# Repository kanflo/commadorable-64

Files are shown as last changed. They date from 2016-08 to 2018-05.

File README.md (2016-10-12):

# Commadorable 64

An adorable Commodore 64 desktop ornament. Blog post [here](http://johan.kanflo.com/the-commadorable-64/).

<p align="center">
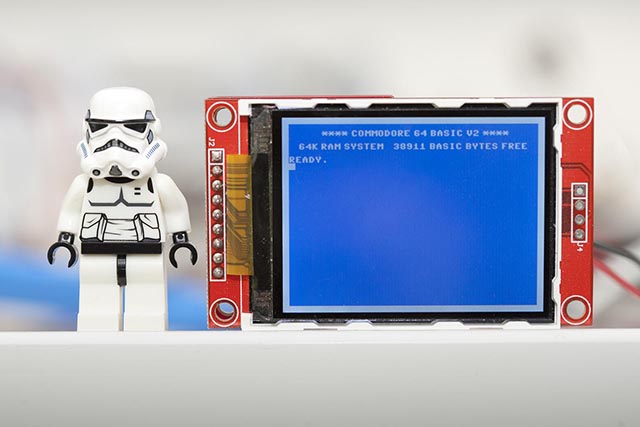
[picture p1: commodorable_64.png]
The Commadorable 64
  
</p>

**Howto**

Assuming you have cloned the EOR git and set your wifi credentials:

```
export EOR_ROOT=/path/to/esp-open-rtos
cd $EOR_ROOT
git clone https://github.com/kanflo/eor-arduino-compat.git extras/arduino-compat
git clone https://github.com/kanflo/eor-adafruit-ili9341.git extras/ili9341
git clone https://github.com/kanflo/eor-cli.git extras/cli
cd /path/to/wherever
git clone https://github.com/kanflo/commadorable-64.git
cd commadorable-64
make -j8 && make flash
```

**Ordering the PCB**

The PCBs can be ordered from DirtyPCBs.com, [without touch](http://dirtypcbs.com/view.php?share=18116&accesskey=5cb9ea9c4754e5c9102b4350393b244e) or [with touch](http://dirtypcbs.com/view.php?share=18114&accesskey=f7144fbd88f9270b40ccc2829f08ee2f). If you use these links to order I will receive a $1 credit :)

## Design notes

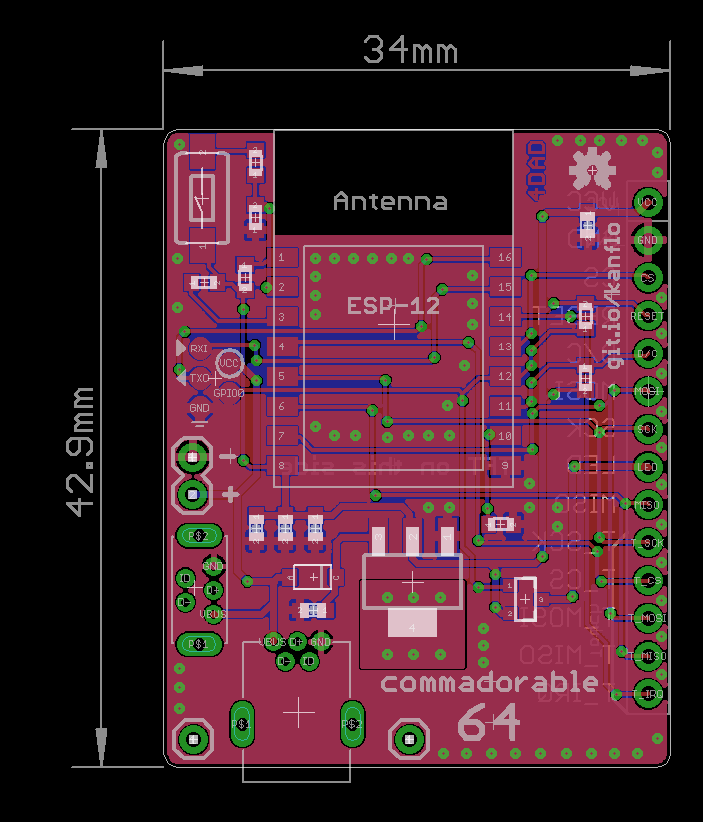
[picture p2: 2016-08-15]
hardware/v1-24-touch/commadorable64-24-touch-v1.png

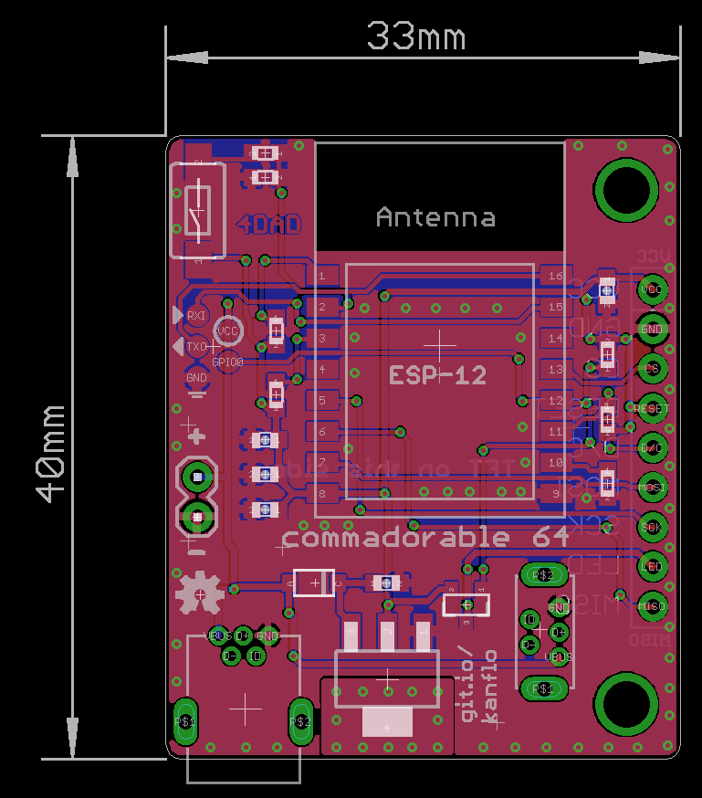
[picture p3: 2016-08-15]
hardware/v1-22/commadorable64-22-v1.png

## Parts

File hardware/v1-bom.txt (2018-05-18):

BOM for Commadoraboe 64 with and without touch

v1-22/        2.2" version without touch
v1-24-touch/  2.4" version with touch
v1-28-touch/  2.8" version with touch

Part Value       Package           Description
------------------------------------------------------------------------------
C1   1uF         0603              Capacitor
C2   0.1uF       0603              Capacitor
C3   1uF         0603              Capacitor
C4   10uF        0603              Capacitor
C5   0.1uF       0603              Capacitor
G1               SOD-123FL         SCHOTTKY DIODE (e.g., MBR120LFST)
J1               1x14              Standard 14-pin 0.1" header
JP1              1X02              Standard 2-pin 0.1" header
JP2, JP3         1X01              For mounting support on C64 touch variant
Q2               SOT23-3           MOSFET-PCHANNEL (e.g.,  IRLML9303)
R1   4k7         R0603             Resistor
R2   4k7         R0603             Resistor
R3   4k7         R0603             Resistor
R4   4k7         R0603             Resistor
R5   4k7         R0603             Resistor
R6   220k        R0603             Resistor
R7   100k        R0603             Resistor
S1               Tactile switch    3x6x2.5mm tactile switch from eBay
U1   3.3V        SOT223            NCP1117ST33 (3.3V LDO)
U2               ESP-12E           ESP12e module
X1                                 Mini USB through hole connector from eBay
X2                                 Vertical Mini USB through hole connector from eBay
X3                                 ESPROG (pads included on PCB, no mounting needed)

Please see http://johan.kanflo.com/the-commadorable-64/ for links to the
switch and USB connectors.

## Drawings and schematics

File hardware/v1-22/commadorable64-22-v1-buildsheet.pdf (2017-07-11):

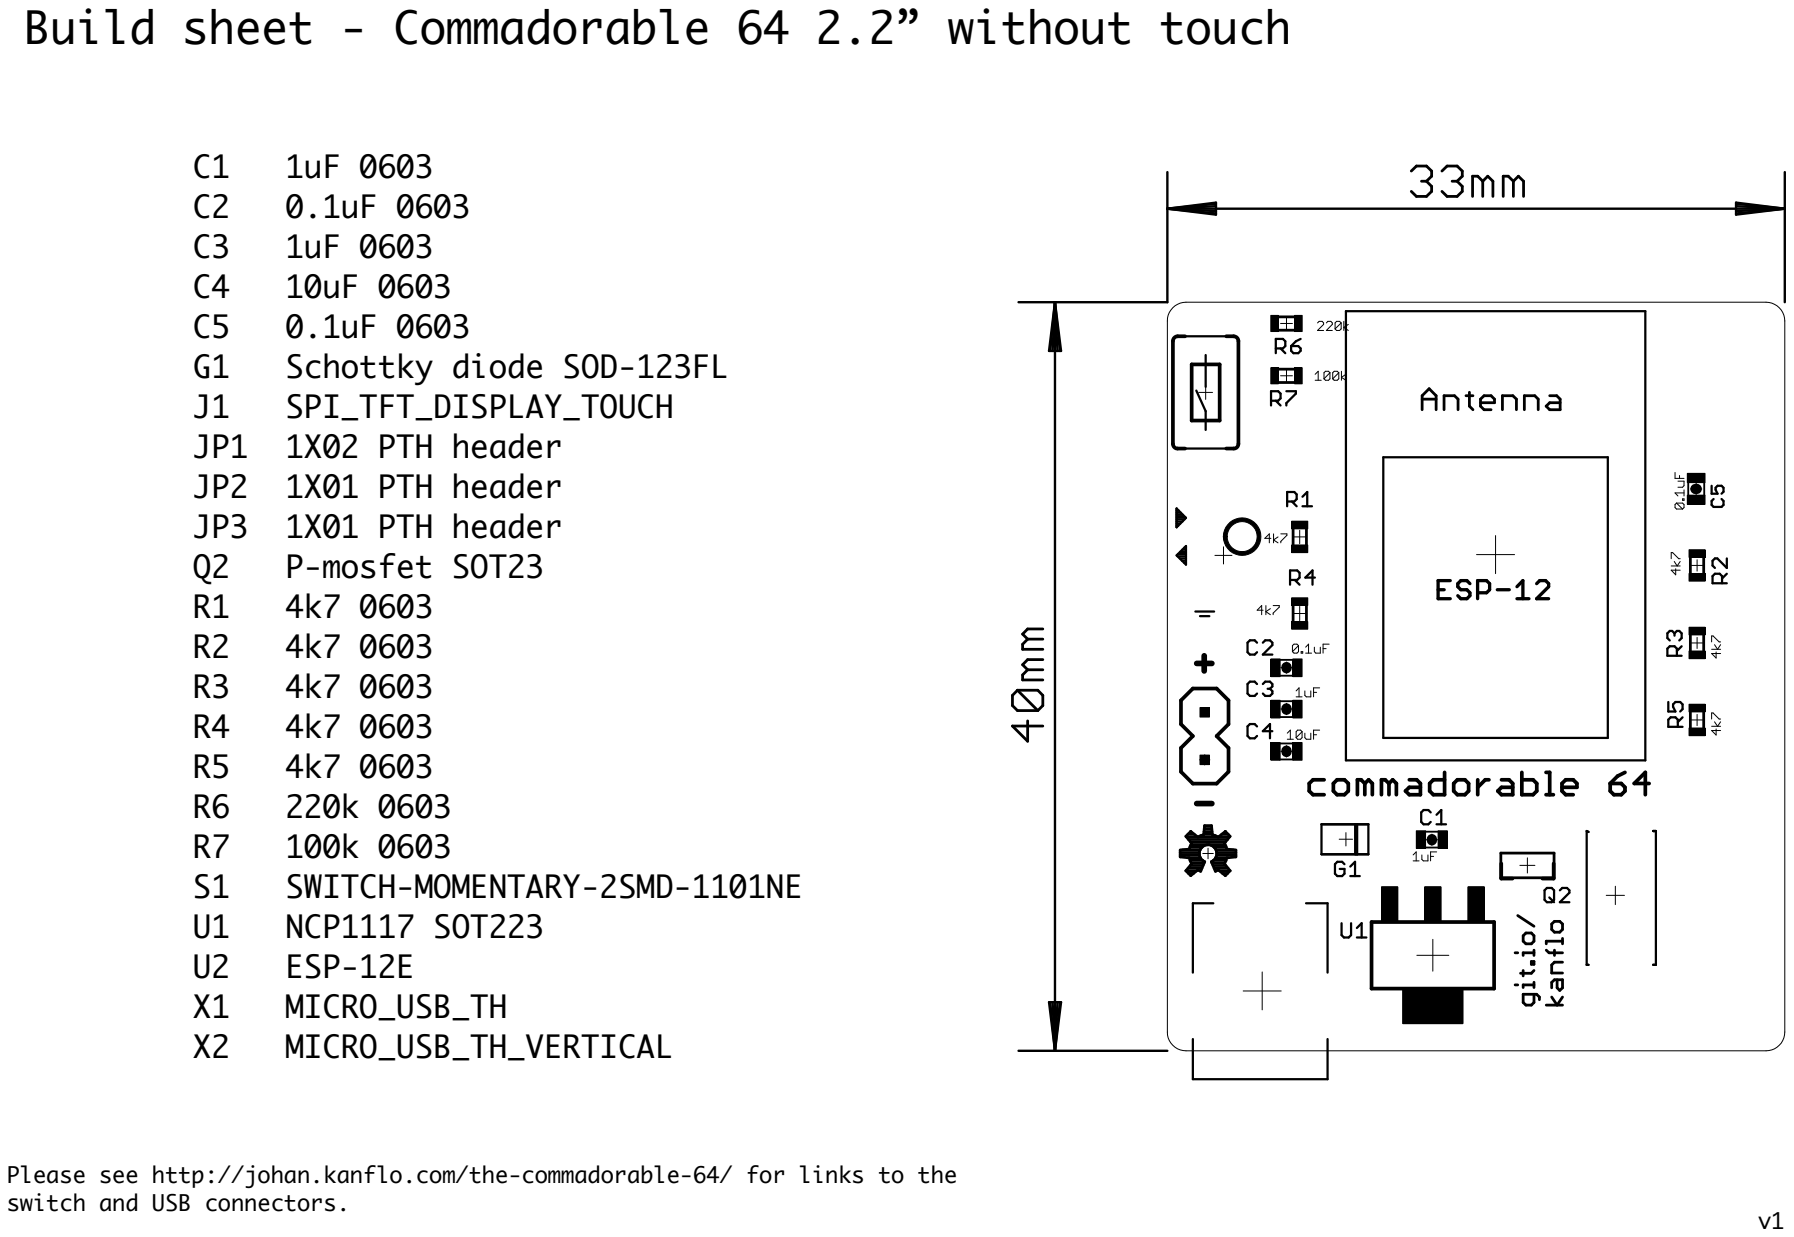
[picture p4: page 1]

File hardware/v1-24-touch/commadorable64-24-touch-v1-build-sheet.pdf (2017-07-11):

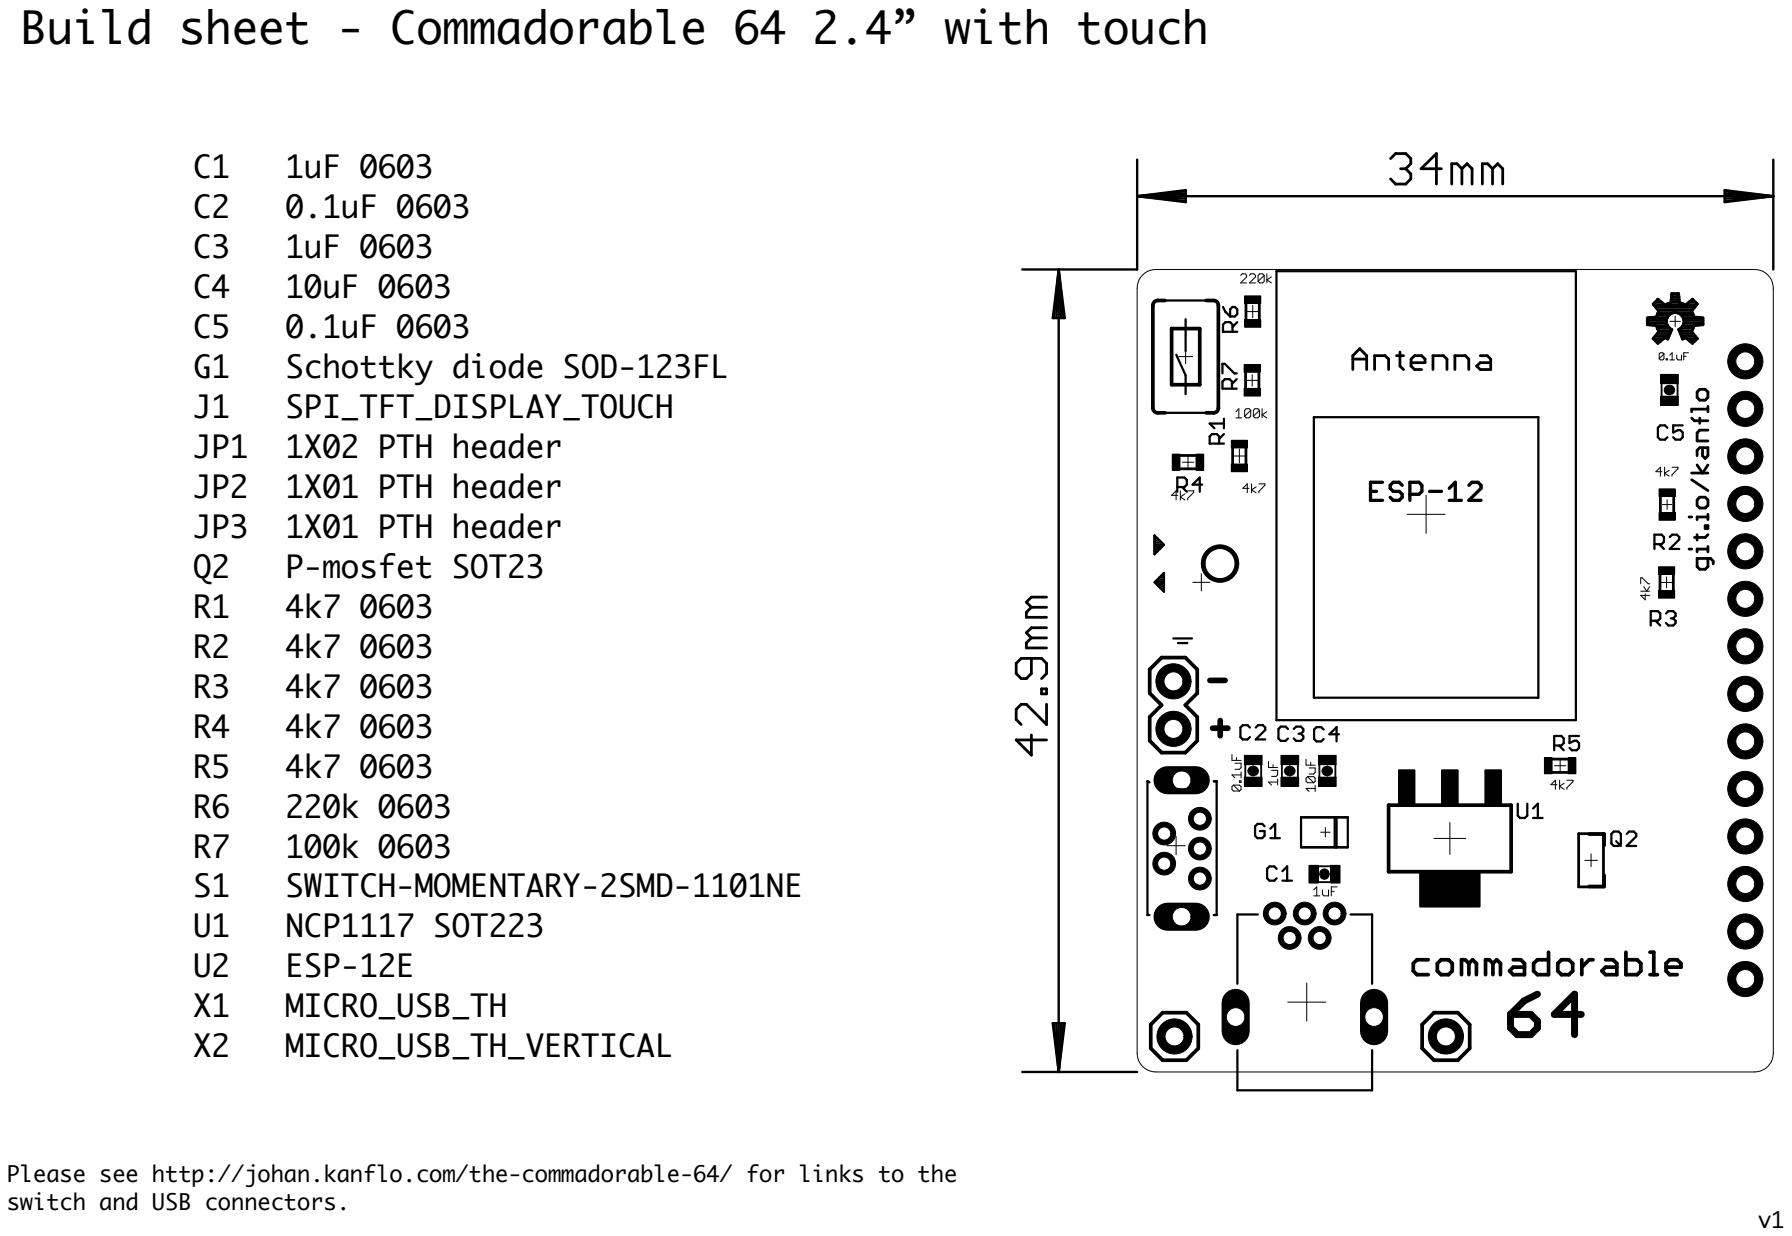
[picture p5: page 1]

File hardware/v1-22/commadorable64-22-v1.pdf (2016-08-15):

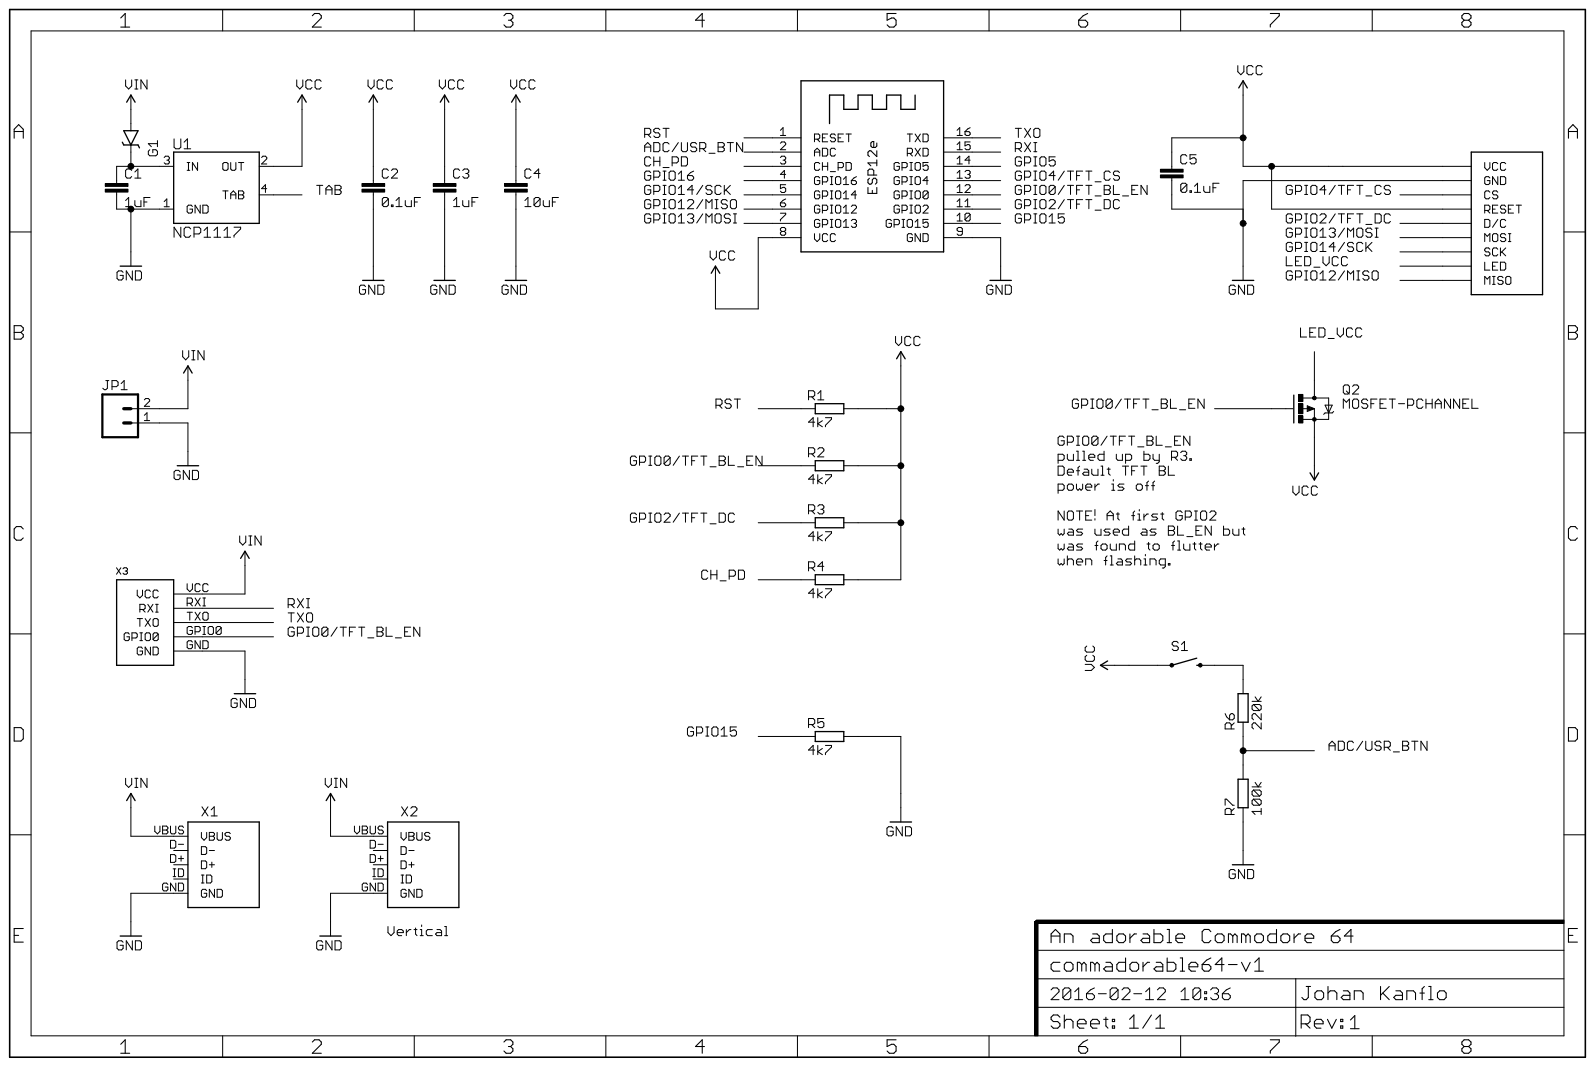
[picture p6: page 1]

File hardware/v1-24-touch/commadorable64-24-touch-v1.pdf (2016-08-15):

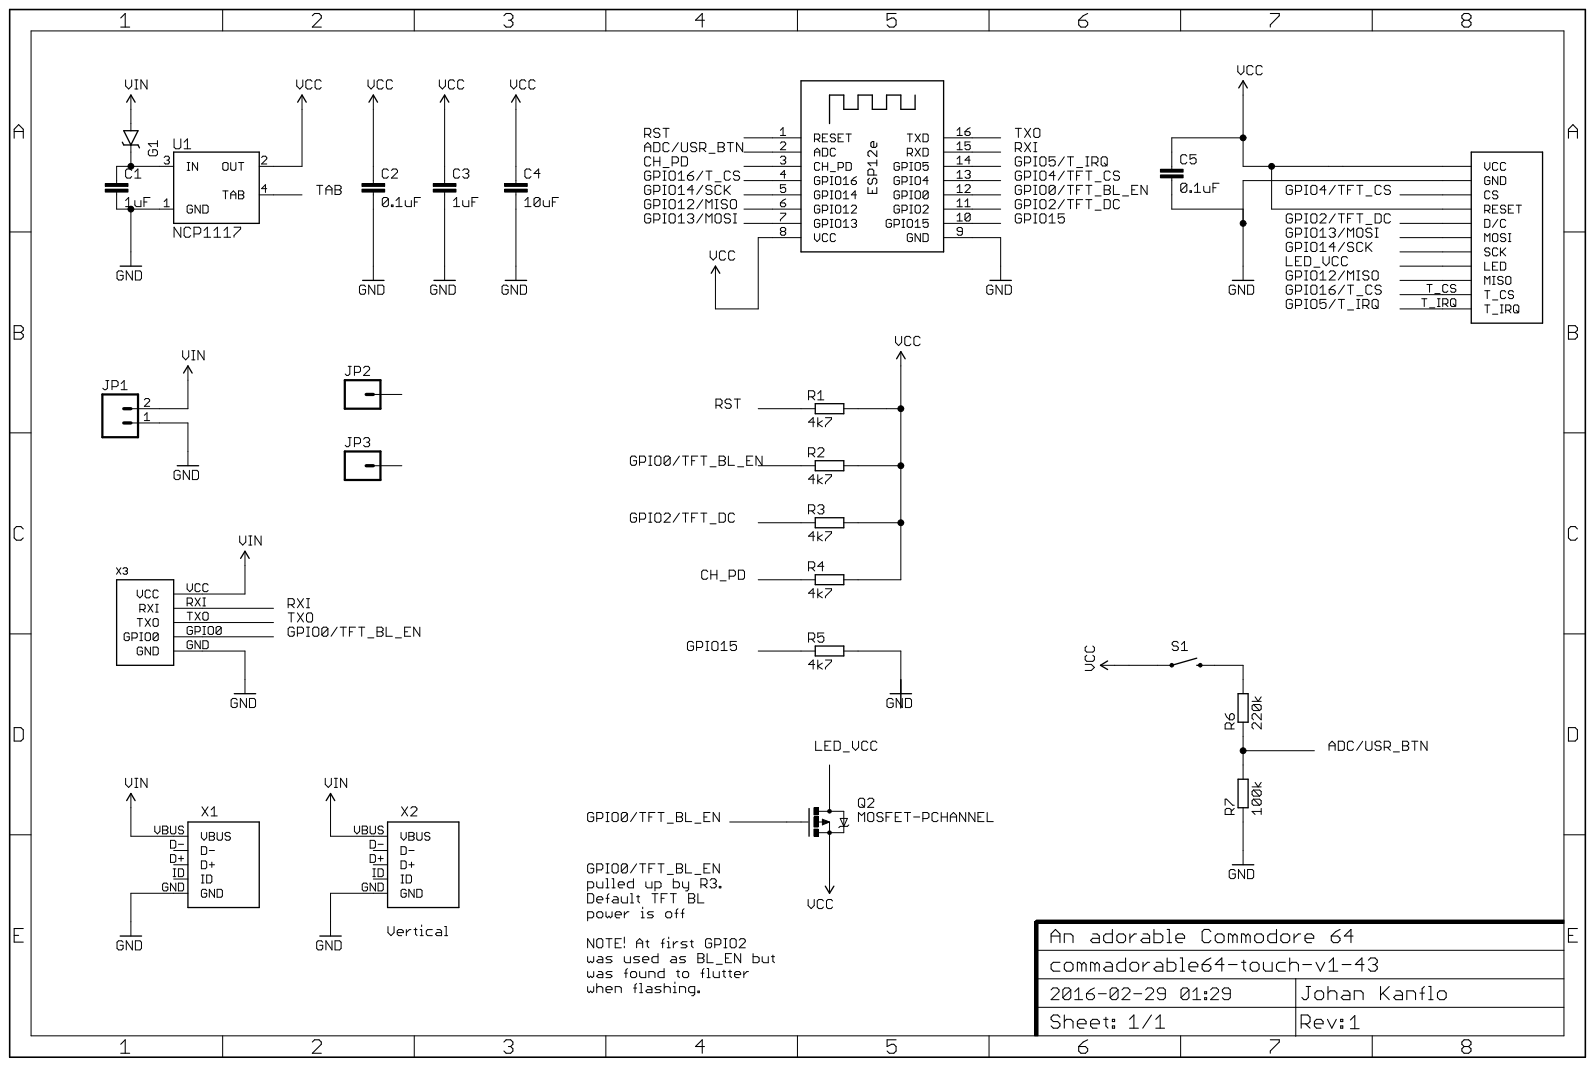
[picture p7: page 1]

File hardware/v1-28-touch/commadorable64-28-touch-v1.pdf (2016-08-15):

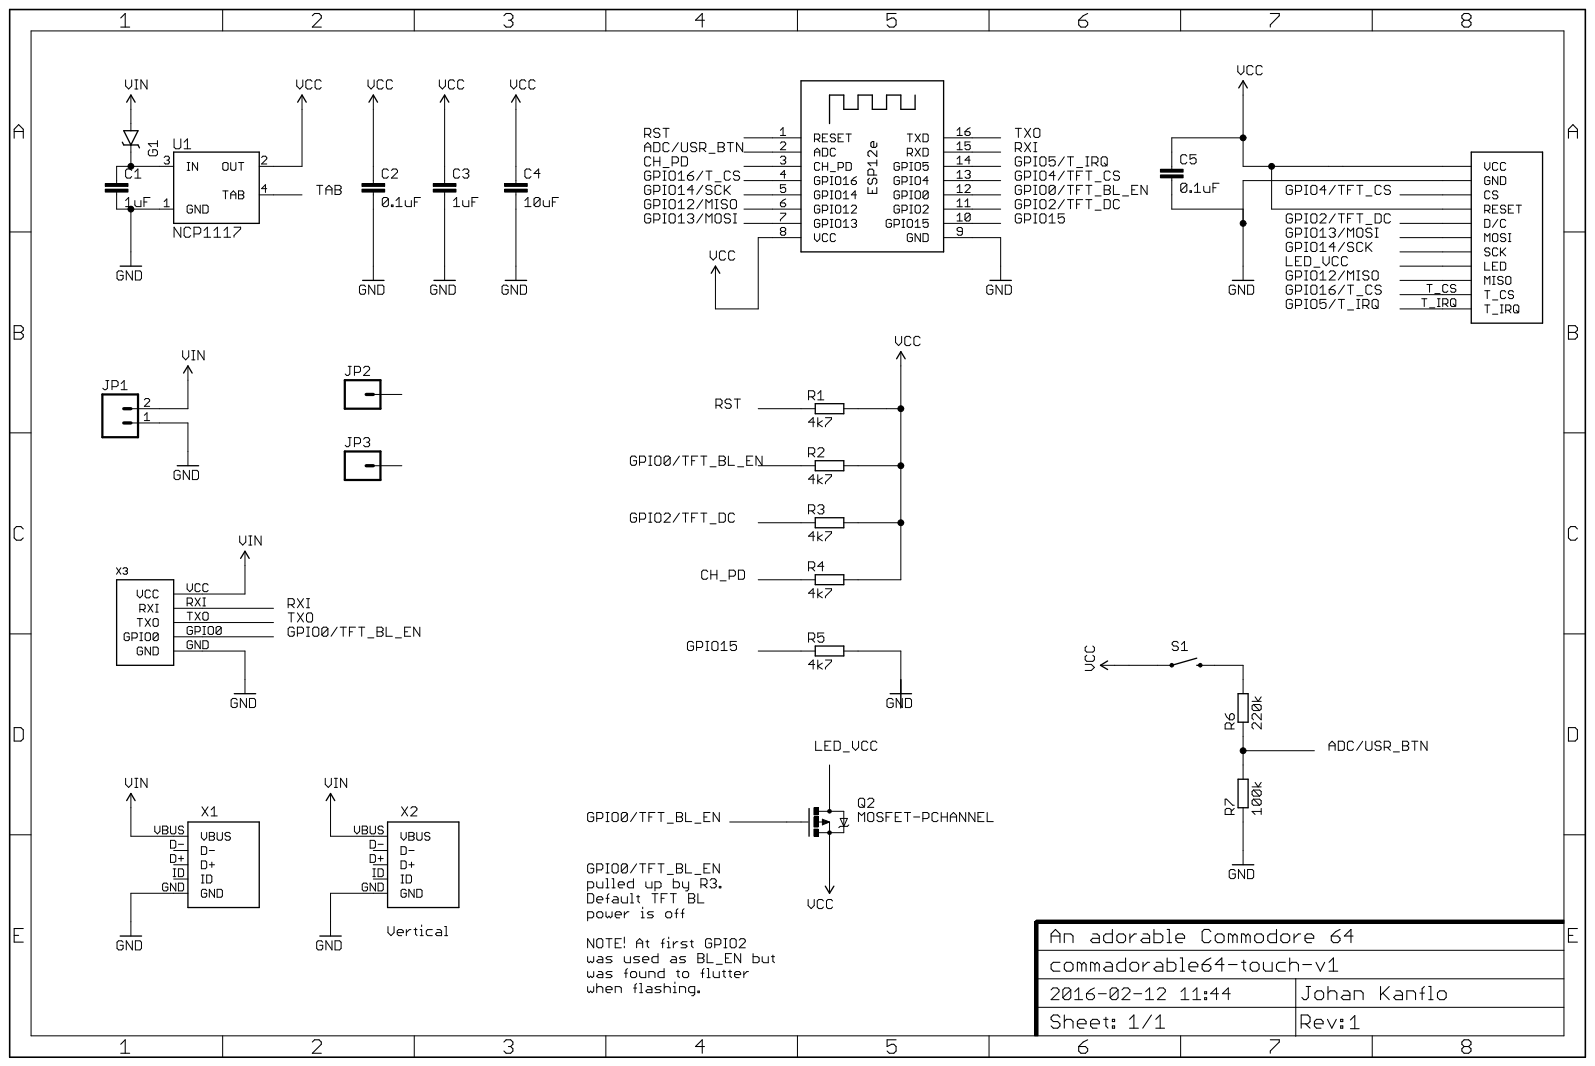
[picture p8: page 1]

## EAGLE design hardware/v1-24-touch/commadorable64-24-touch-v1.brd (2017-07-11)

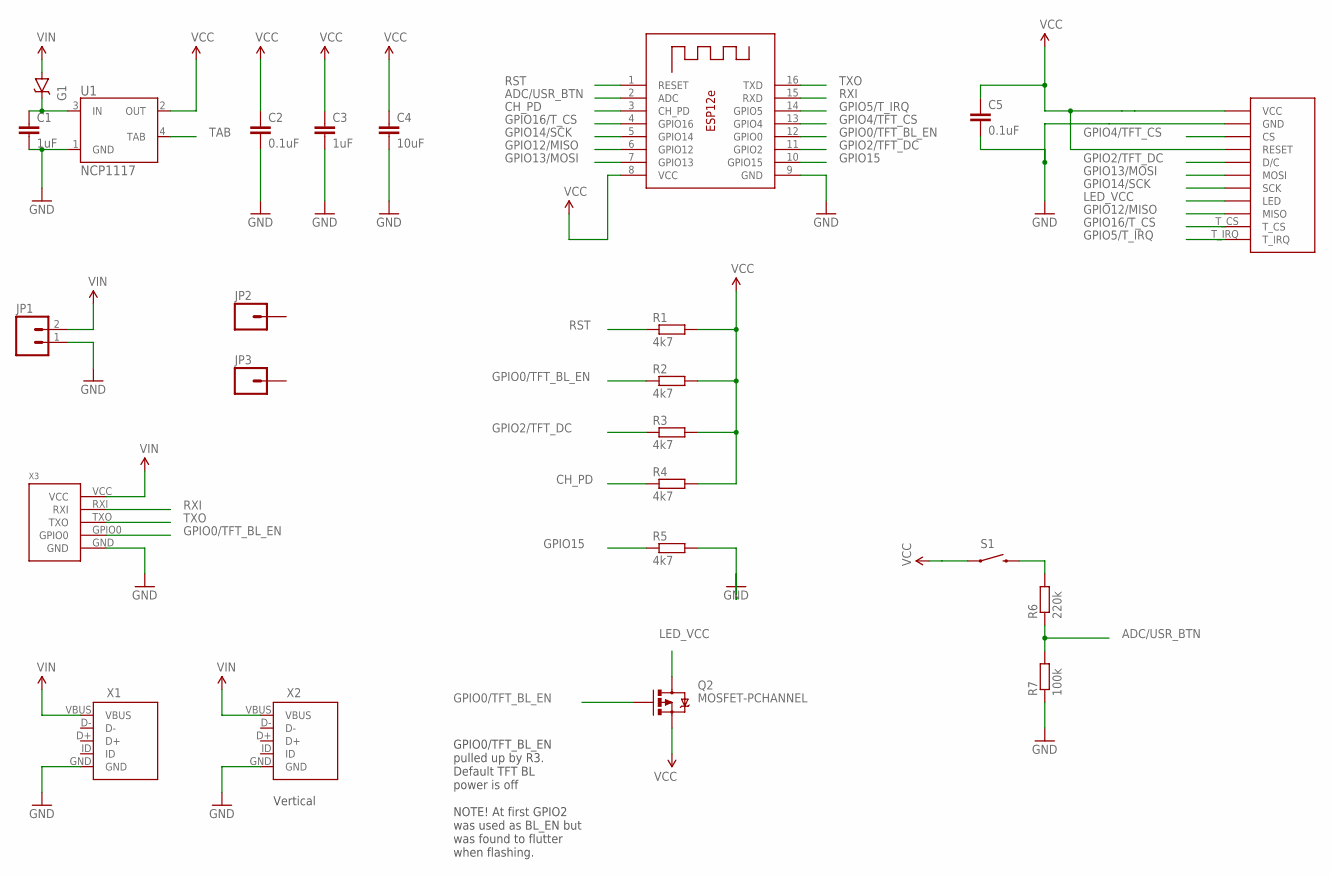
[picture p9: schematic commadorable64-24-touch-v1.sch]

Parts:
C1, C3: 1uF; 0603-CAP
C2, C5: 0.1uF; 0603-CAP
C4: 10uF; 0603-CAP
G1: DIODE-SCHOTTKYSOD-123FL; SOD-123FL
J1: SPI_TFT_DISPLAY_TOUCH; SPI_DISPLAY_TOUCH
JP1: M02PTH; 1X02
JP2, JP3: M01PTH; 1X01
Q2: MOSFET-PCHANNEL; SOT23-3
R1, R2, R3, R4, R5: 4k7; R0603
R6: 220k; R0603
R7: 100k; R0603
S1: SWITCH-MOMENTARY-2SMD-1101NE; TACTILE-SWITCH-1101NE
U1: NCP1117; SOT223
U2: ESP-12E
X1: MICRO_USB_TH
X2: MICRO_USB_TH_VERTICAL
X3: ESPROGESPROG-DEVICE; ESPROG

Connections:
ADC/USR_BTN: R6.1, R7.2, U2.2 (ADC)
CH_PD: R4.1, U2.3 (CH_PD)
GND: C1.2, C2.2, C3.2, C4.2, C5.2, J1.GND, JP1.1, R5.2, R7.1, U1.1 (GND), U2.9 (GND), X1.GND, X2.GND, X3.GND
GPIO0/TFT_BL_EN: Q2.1 (G), R2.1, U2.12 (GPIO0), X3.GPIO0
GPIO2/TFT_DC: J1.D/C, R3.1, U2.11 (GPIO2)
GPIO4/TFT_CS: J1.CS, U2.13 (GPIO4)
GPIO5/T_IRQ: J1.T_IRQ, U2.14 (GPIO5)
GPIO12/MISO: J1.MISO, J1.T_MISO (MISO), U2.6 (GPIO12)
GPIO13/MOSI: J1.MOSI, J1.T_MOSI (MOSI), U2.7 (GPIO13)
GPIO14/SCK: J1.SCK, J1.T_SCK (SCK), U2.5 (GPIO14)
GPIO15: R5.1, U2.10 (GPIO15)
GPIO16/T_CS: J1.T_CS, U2.4 (GPIO16)
LED_VCC: J1.LED, Q2.3 (D)
unnamed: C1.1, G1.C, U1.3 (IN)
unnamed: R6.2, S1.2
RST: R1.1, U2.1 (RESET)
RXI: U2.15 (RXD), X3.RXI
TAB: U1.4 (TAB)
TXO: U2.16 (TXD), X3.TXO
VCC: C2.1, C3.1, C4.1, C5.1, J1.RESET, J1.VCC, Q2.2 (S), R1.2, R2.2, R3.2, R4.2, S1.1, U1.2 (OUT), U2.8 (VCC)
VIN: G1.A, JP1.2, X1.VBUS, X2.VBUS, X3.VCC

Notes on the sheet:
GPIO0/TFT_BL_EN pulled up by R3. Default TFT BL power is off NOTE! At first GPIO2 was used as BL_EN but was found to flutter when flashing.
Vertical

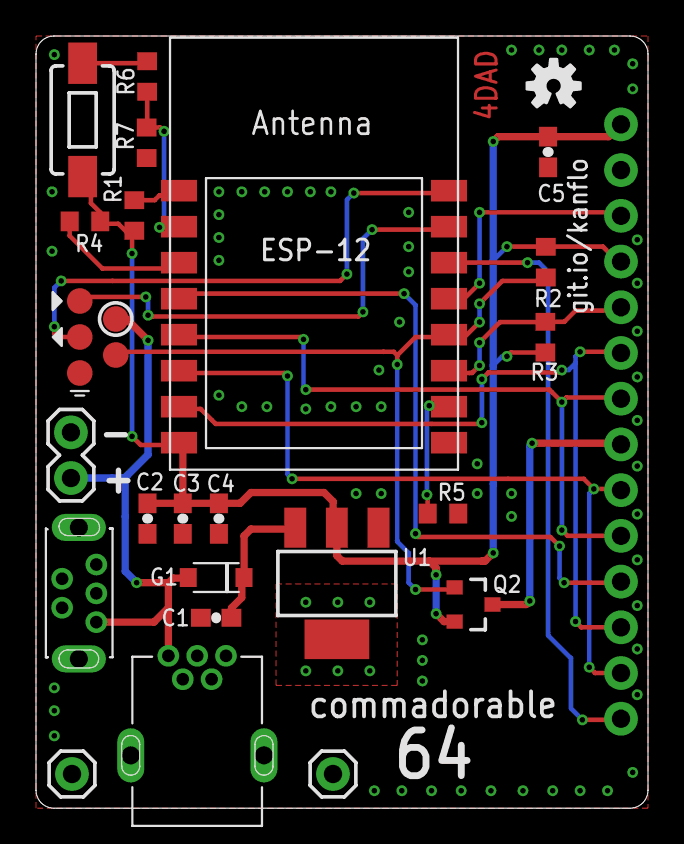
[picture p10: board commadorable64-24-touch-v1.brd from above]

Board: 2 copper layers, 34.0 x 42.9 mm, 25 parts (1 on the bottom side), 20 nets.

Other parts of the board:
U$1: OSHW-LOGO-S

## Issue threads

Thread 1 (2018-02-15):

LCD flickering

abdollahpour, 2018-02-15:
First of all, I want to say thanks for the great project shared.
It works well, I just have one annoying issue that I can not solve. The LCD flickers so much when I use USB power from my Laptop, it's much better with direct charger. Is there any way to fix it?

abdollahpour, 2018-02-20:
Understood, thanks

Closed 2018-02-20.

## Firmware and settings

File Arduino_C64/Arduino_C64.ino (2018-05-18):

#include <Arduino.h>
#include <SPI.h>
#include <Adafruit_ILI9341.h>
#include <Adafruit_GFX.h>
#include <FS.h>
// XPT2046 Lib @  https://github.com/spapadim/XPT2046
#include <XPT2046.h>


// GPIO mapping
#define TFT_DC     2
#define TFT_CS     4
#define TFT_BL     0
#define TOUCH_CS  16
#define TOUCH_IRQ  5

Adafruit_ILI9341 tft = Adafruit_ILI9341(TFT_CS, TFT_DC);

//#define TOUCH

#ifdef TOUCH
XPT2046 touch(TOUCH_CS, TOUCH_IRQ);
#endif // TOUCH


void bl_on(bool on)
{
  digitalWrite(TFT_BL, on ? LOW : HIGH);
}

void bmpDraw(char *filename, uint16_t x, uint16_t y);
uint16_t read16(File & f);
uint32_t read32(File & f);

/**************************************************************************/
/*!
    @brief  Converts a 24-bit RGB color to an equivalent 16-bit RGB565 value

    @param[in]  r  8-bit red
    @param[in]  g  8-bit green
    @param[in]  b  8-bit blue

    @section Example

    @code 

    // Get 16-bit equivalent of 24-bit color
    uint16_t gray = drawRGB24toRGB565(0x33, 0x33, 0x33);

    @endcode
*/
/**************************************************************************/
uint16_t drawRGB24toRGB565(uint8_t r, uint8_t g, uint8_t b)
{
  return ((r / 8) << 11) | ((g / 4) << 5) | (b / 8);
}

void spiffs_ls()
{
  Dir dir = SPIFFS.openDir("/");
  while (dir.next()) {
      Serial.print(dir.fileName());
      Serial.printf("  ");
      File f = dir.openFile("r");
      Serial.println(f.size());
  }
}

void setup()
{
//  attachInterrupt(digitalPinToInterrupt(TOUCH_IRQ), touch_irq, RISING);
  SPI.setFrequency(1000000);

  pinMode(TFT_BL, OUTPUT);
  bl_on(false);

  Serial.begin(115200);
  Serial.println("");
  Serial.println("");
  Serial.println("    *** Commadorable  64 Basic V2 ***");
  Serial.println(" 64K system RAM, 38911 BASIC bytes free.");
  Serial.println("");

  
  SPIFFS.begin();
  spiffs_ls();

  tft.begin();
  tft.fillScreen(ILI9341_BLUE);
#ifdef TOUCH
  touch.begin(320, 240);  // Must be done before setting rotation
//  touch.setRotation(touch.ROT270);
//  touch.setCalibration(209, 1759, 1775, 273);
#endif // TOUCH

  bmpDraw((char*) "/c64.bmp", 0, 0);
  bl_on(true);


  Serial.println("READY");
}

void loop(void)
{
#ifdef TOUCH
  if (touch.isTouching()) {
    uint16_t x, y;
//    touch.getRaw (x, y, touch.MODE_DFR, 1);
    touch.getPosition(x, y);
    Serial.print(x);
    Serial.print(" ");
    Serial.println(y);
    delay(80);
  }
#else // TOUCH
  uint16_t light = drawRGB24toRGB565(165, 165, 175);
  uint16_t dark  = drawRGB24toRGB565( 66,  66, 231);
  tft.fillRect(56, 304, 8, 8, light);
  delay(800);
  tft.fillRect(56, 304, 8, 8, dark);
  delay(800);
#endif // TOUCH
}

#define BUFFPIXEL 20

void bmpDraw(char *filename, uint16_t x, uint16_t y)
{
  File     bmpFile;
  int      bmpWidth, bmpHeight;   // W+H in pixels
  uint8_t  bmpDepth;              // Bit depth (currently must be 24)
  uint32_t bmpImageoffset;        // Start of image data in file
  uint32_t rowSize;               // Not always = bmpWidth; may have padding
  uint8_t  sdbuffer[3*BUFFPIXEL]; // pixel buffer (R+G+B per pixel)
  uint8_t  buffidx = sizeof(sdbuffer); // Current position in sdbuffer
  boolean  goodBmp = false;       // Set to true on valid header parse
  boolean  flip    = true;        // BMP is stored bottom-to-top
  int      w, h, row, col;
  uint8_t  r, g, b;
  uint32_t pos = 0, startTime = millis();

  if((x >= tft.width()) || (y >= tft.height())) return;

  Serial.println();
  Serial.print("Loading image '");
  Serial.print(filename);
  Serial.println('\'');

  // Open requested file on SD card
  bmpFile = SPIFFS.open(filename, "r");
  if (!bmpFile) {
    Serial.println("File not found");
    return;
  }

  // Parse BMP header
  if(read16(bmpFile) == 0x4D42) { // BMP signature
    Serial.print("File size: "); Serial.println(read32(bmpFile));
    (void)read32(bmpFile); // Read & ignore creator bytes
    bmpImageoffset = read32(bmpFile); // Start of image data
    Serial.print("Image Offset: "); Serial.println(bmpImageoffset, DEC);
    // Read DIB header
    Serial.print("Header size: "); Serial.println(read32(bmpFile));
    bmpWidth  = read32(bmpFile);
    bmpHeight = read32(bmpFile);
    if(read16(bmpFile) == 1) { // # planes -- must be '1'
      bmpDepth = read16(bmpFile); // bits per pixel
      Serial.print("Bit Depth: "); Serial.println(bmpDepth);
      if((bmpDepth == 24) && (read32(bmpFile) == 0)) { // 0 = uncompressed

        goodBmp = true; // Supported BMP format -- proceed!
        Serial.print("Image size: ");
        Serial.print(bmpWidth);
        Serial.print('x');
        Serial.println(bmpHeight);

        // BMP rows are padded (if needed) to 4-byte boundary
        rowSize = (bmpWidth * 3 + 3) & ~3;

        // If bmpHeight is negative, image is in top-down order.
        // This is not canon but has been observed in the wild.
        if(bmpHeight < 0) {
          bmpHeight = -bmpHeight;
          flip      = false;
        }

        // Crop area to be loaded
        w = bmpWidth;
        h = bmpHeight;
        if((x+w-1) >= tft.width())  w = tft.width()  - x;
        if((y+h-1) >= tft.height()) h = tft.height() - y;

        // Set TFT address window to clipped image bounds
        tft.setAddrWindow(x, y, x+w-1, y+h-1);

        for (row=0; row<h; row++) { // For each scanline...

          // Seek to start of scan line.  It might seem labor-
          // intensive to be doing this on every line, but this
          // method covers a lot of gritty details like cropping
          // and scanline padding.  Also, the seek only takes
          // place if the file position actually needs to change
          // (avoids a lot of cluster math in SD library).
          if(flip) // Bitmap is stored bottom-to-top order (normal BMP)
            pos = bmpImageoffset + (bmpHeight - 1 - row) * rowSize;
          else     // Bitmap is stored top-to-bottom
            pos = bmpImageoffset + row * rowSize;
          if(bmpFile.position() != pos) { // Need seek?
            bmpFile.seek(pos, SeekSet);
            buffidx = sizeof(sdbuffer); // Force buffer reload
          }

          for (col=0; col<w; col++) { // For each pixel...
            // Time to read more pixel data?
            if (buffidx >= sizeof(sdbuffer)) { // Indeed
              bmpFile.read(sdbuffer, sizeof(sdbuffer));
              buffidx = 0; // Set index to beginning
            }

            // Convert pixel from BMP to TFT format, push to display
            b = sdbuffer[buffidx++];
            g = sdbuffer[buffidx++];
            r = sdbuffer[buffidx++];
            tft.pushColor(drawRGB24toRGB565(r,g,b));
          } // end pixel
        } // end scanline
        Serial.print("Loaded in ");
        Serial.print(millis() - startTime);
        Serial.println(" ms");
      } // end goodBmp
    }
  }

  bmpFile.close();
  if(!goodBmp) {
    Serial.println("BMP format not recognized.");
  }
}

// These read 16- and 32-bit types from the SD card file.
// BMP data is stored little-endian, Arduino is little-endian too.
// May need to reverse subscript order if porting elsewhere.

uint16_t read16(File & f)
{
  uint16_t result;
  ((uint8_t *)&result)[0] = f.read(); // LSB
  ((uint8_t *)&result)[1] = f.read(); // MSB
  return result;
}

uint32_t read32(File & f)
{
  uint32_t result;
  ((uint8_t *)&result)[0] = f.read(); // LSB
  ((uint8_t *)&result)[1] = f.read();
  ((uint8_t *)&result)[2] = f.read();
  ((uint8_t *)&result)[3] = f.read(); // MSB
  return result;
}

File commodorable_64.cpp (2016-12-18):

/* 
 * The MIT License (MIT)
 * 
 * Copyright (c) 2016 Johan Kanflo (github.com/kanflo)
 * 
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
 * THE SOFTWARE IS PROVIDED "AS IS", WITHOUT WARRANTY OF ANY KIND, EXPRESS OR
 * IMPLIED, INCLUDING BUT NOT LIMITED TO THE WARRANTIES OF MERCHANTABILITY,
 * FITNESS FOR A PARTICULAR PURPOSE AND NONINFRINGEMENT. IN NO EVENT SHALL THE
 * AUTHORS OR COPYRIGHT HOLDERS BE LIABLE FOR ANY CLAIM, DAMAGES OR OTHER
 * LIABILITY, WHETHER IN AN ACTION OF CONTRACT, TORT OR OTHERWISE, ARISING FROM,
 * OUT OF OR IN CONNECTION WITH THE SOFTWARE OR THE USE OR OTHER DEALINGS IN
 * THE SOFTWARE.
 */

#include <stdlib.h>
#include <espressif/esp_common.h>
#include <esp/uart.h> 
#include <FreeRTOS.h>
#include <task.h>
#include <semphr.h>
#include <esp8266.h>
#include <esp/spi.h>
#include <ssid_config.h>
#include <Adafruit_GFX.hpp>
#include <Adafruit_ILI9341.hpp>
#include <SPI.hpp>

extern "C" {
  #include <ota-tftp.h>
  #include <cli.h>
  #include "c64.h"
}

#define TFT_CS 4
#define TFT_DC 2
#define TFT_LED 0

#define ADC_BUTTON_PRESSED (1000) // adc > ADC_BUTTON_PRESSED when button pressed

SemaphoreHandle_t gTFTSemaphore;
Adafruit_ILI9341 tft = Adafruit_ILI9341(TFT_CS, TFT_DC);

#define delay_ms(ms) vTaskDelay(ms / portTICK_PERIOD_MS)

extern "C" {

// Convert a 24-bit RGB color to an equivalent 16-bit RGB565 value
static __inline uint16_t rgb565(uint8_t r, uint8_t g, uint8_t b)
{
//    return ((r / 8) << 11) | ((g / 4) << 5) | (b / 8);
    return ((r & 0xF8) << 8) | ((g & 0xFC) << 3) | (b >> 3);
}

static __inline uint16_t read16(uint8_t *bmp, uint32_t *pos)
{
    uint16_t result;
    ((uint8_t *)&result)[0] = bmp[(*pos)++];  // LSB
    ((uint8_t *)&result)[1] = bmp[(*pos)++];  // MSB
    return result;
}

static __inline uint32_t read32(uint8_t *bmp, uint32_t *pos)
{
    uint32_t result;
    ((uint8_t *)&result)[0] = bmp[(*pos)++];  // LSB
    ((uint8_t *)&result)[1] = bmp[(*pos)++];
    ((uint8_t *)&result)[2] = bmp[(*pos)++];
    ((uint8_t *)&result)[3] = bmp[(*pos)++];  // MSB
    return result;
}

static void bmp_draw(uint8_t *bmp, uint16_t x, uint16_t y)
{
    uint32_t bmp_pos = 0;
    int      bmp_width, bmp_height;   // W+H in pixels
    uint8_t  bmp_depth;               // Bit depth (currently must be 24)
    uint32_t img_offset;              // Start of image data in file
    uint32_t row_size;                // Not always = bmp_width; may have padding
    boolean  good_bmp = false;        // Set to true on valid header parse
    boolean  flip    = true;          // BMP is stored bottom-to-top
    int      w, h, row, col;
    uint8_t  r, g, b;
    uint32_t pos = 0;
    uint32_t img_size;

    if (xSemaphoreTake(gTFTSemaphore, 500 / portTICK_PERIOD_MS) == pdFALSE) {
        printf("Timeout acquiring TFT semaphore\n");
        return;
    }
    if((x >= tft.width()) || (y >= tft.height())) return;


    // Parse BMP header
    if(read16(bmp, &bmp_pos) == 0x4D42) { // BMP signature
        img_size = read32(bmp, &bmp_pos);
        (void) read32(bmp, &bmp_pos); // Read & ignore creator bytes
        img_offset = read32(bmp, &bmp_pos); // Start of image data
        // Read DIB header
        (void) read32(bmp, &bmp_pos); // Header size
        bmp_width  = read32(bmp, &bmp_pos);
        bmp_height = read32(bmp, &bmp_pos);
        if(read16(bmp, &bmp_pos) == 1) { // # planes -- must be '1'
            bmp_depth = read16(bmp, &bmp_pos); // bits per pixel
            if((bmp_depth == 24) && (read32(bmp, &bmp_pos) == 0)) { // 0 = uncompressed
                good_bmp = true; // Supported BMP format -- proceed!
                printf("Image dimensions: %d x %d  %d bit  %d bytes\n", bmp_width, bmp_height, bmp_depth, img_size);
                // BMP rows are padded (if needed) to 4-byte boundary
                row_size = (bmp_width * 3 + 3) & ~3;

                // If bmp_height is negative, image is in top-down order.
                // This is not canon but has been observed in the wild.
                if(bmp_height < 0) {
                    bmp_height = -bmp_height;
                    flip = false;
                }

                // Crop area to be loaded
                w = bmp_width;
                h = bmp_height;
                if((x+w-1) >= tft.width())  w = tft.width()  - x;
                if((y+h-1) >= tft.height()) h = tft.height() - y;

                // Set TFT address window to clipped image bounds
                tft.setAddrWindow(x, y, x+w-1, y+h-1);

                gpio_write(TFT_DC, true); // @todo: should be done in setAddrWindow imho
                gpio_write(TFT_CS, false);
                for (row=0; row<h; row++) { // For each scanline...

                    // Seek to start of scan line.  It might seem labor-
                    // intensive to be doing this on every line, but this
                    // method covers a lot of gritty details like cropping
                    // and scanline padding.  Also, the seek only takes
                    // place if the file position actually needs to change
                    // (avoids a lot of cluster math in SD library).
                    if(flip) // Bitmap is stored bottom-to-top order (normal BMP)
                        pos = img_offset + (bmp_height - 1 - row) * row_size;
                    else     // Bitmap is stored top-to-bottom
                        pos = img_offset + row * row_size;
                    for (col=0; col<w; col++) { // For each pixel...
                        // Convert pixel from BMP to TFT format, push to display
                        b = bmp[pos++];
                        g = bmp[pos++];
                        r = bmp[pos++];
                        uint16_t temp = ((r / 8) << 11) | ((g / 4) << 5) | (b / 8);
                        temp = temp >> 8 | temp << 8;
                        (void) spi_transfer_16(1, temp); // Faster than tft.pushColor(rgb565(r,g,b));
                    }
                }
                gpio_write(TFT_CS, true);
            }
        }
    }

    if(!good_bmp) {
        char msg[64];
        snprintf((char*) msg, sizeof(msg), "No BMP found at 0x%08x", (uint32_t) bmp);
        tft.fillScreen(ILI9341_BLACK);
        tft.setCursor(50, 100);
        tft.setTextColor(ILI9341_RED);
        tft.print((char*) msg);
        printf("BMP format not recognized.\n");
    }
    xSemaphoreGive(gTFTSemaphore);
}
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

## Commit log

2016-08-15 Added schematics
    [commadorable64-touch-v1-43.brd, commadorable64-touch-v1-43.sch, commadorable64-touch-v1.brd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]
2016-08-23 Added ESP8266 Arduino version of the Commadorable 64 demo
2016-08-28 Added BOM
2017-07-11 Renamed boards for TFT size clarity
    [commadorable64-22-v1.brd, commadorable64-22-v1.sch, commadorable64-24-touch-v1.brd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]
2017-07-11 Added silkscreen, separated R6, R7
    [commadorable64-22-v1.brd]
2017-07-11 Added silkscreen
    [commadorable64-24-touch-v1.brd]
2017-07-11 Added build sheets to aid PCB mounting
2017-11-24 Update v1-bom.txt
    added and redo some descritption
2017-11-24 add comment to the XPT2046 Library
    add Link to the XPT2046 Lib cause it is not in the Arduino Library Manager

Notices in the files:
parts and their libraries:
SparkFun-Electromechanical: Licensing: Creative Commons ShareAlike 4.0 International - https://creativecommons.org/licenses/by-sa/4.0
